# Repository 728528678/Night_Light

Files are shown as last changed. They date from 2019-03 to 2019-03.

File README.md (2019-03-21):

# Night_Light - The darkness need some light

## Night Light 是一个简单、灵活的小夜灯项目,要完成它你可能需要准备以下材料

### 元件清单
* 主控:		STM32F030F4P6		*1
* 触摸芯片:	TTP233D-HA6			*2
* 三极管: 	8050	*1 	8550	*1
* 降压芯片:	AMS1117 3.3v		*1
* 电容:		100nF	*15	100pF	*2
* USB转TTL:	CH340C				*1
* 二极管:	1N4148				*1
* 接插件:	4p排座	*1	4p排针	*1
* led灯:	白色贴片led			*4
* 电阻:		10KΩ	*6	1KΩ		*7
* USB接口:	TypeC 16pin 母座	*1
* 灯珠:		ws2812				*8
* 主控板:	NL_CTL2.0			*1
* 灯板:		NL_RGB2.0			*1

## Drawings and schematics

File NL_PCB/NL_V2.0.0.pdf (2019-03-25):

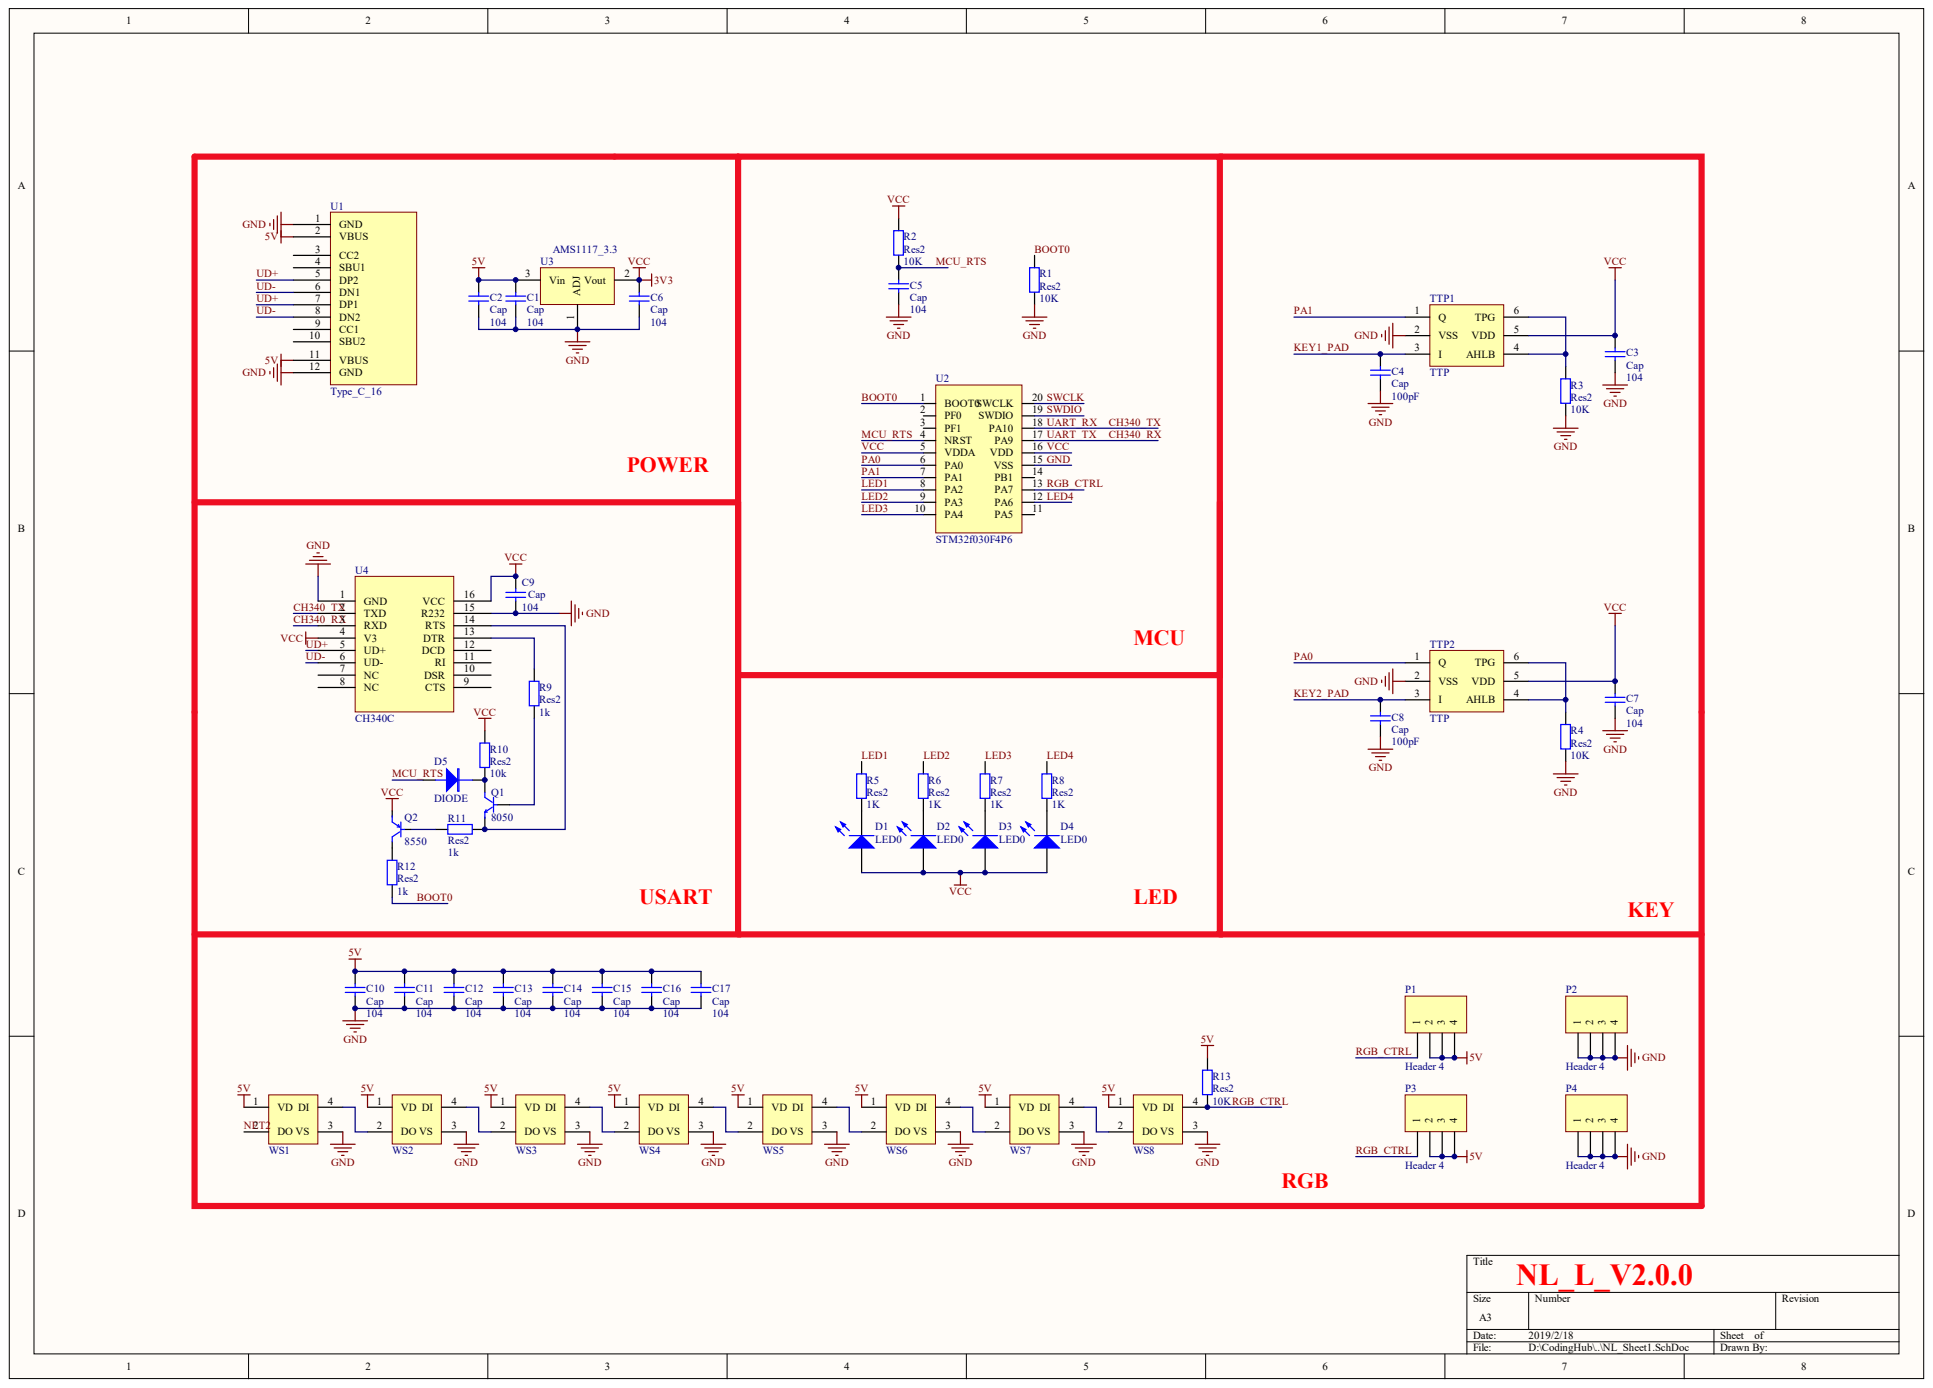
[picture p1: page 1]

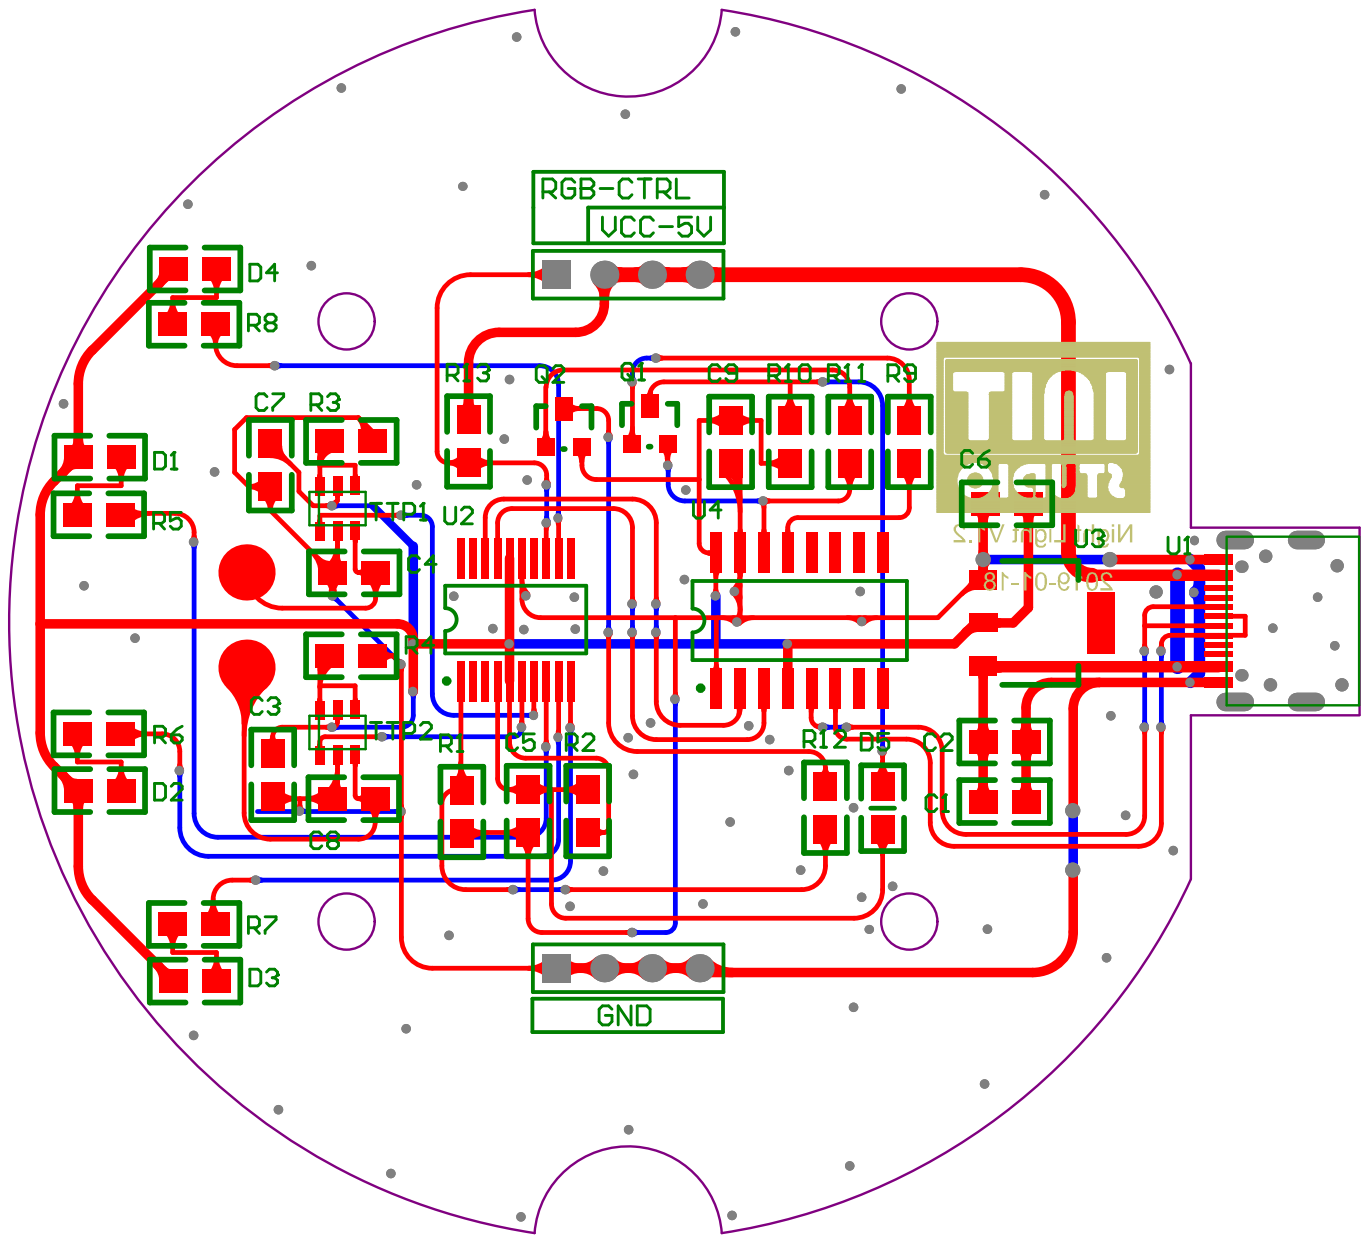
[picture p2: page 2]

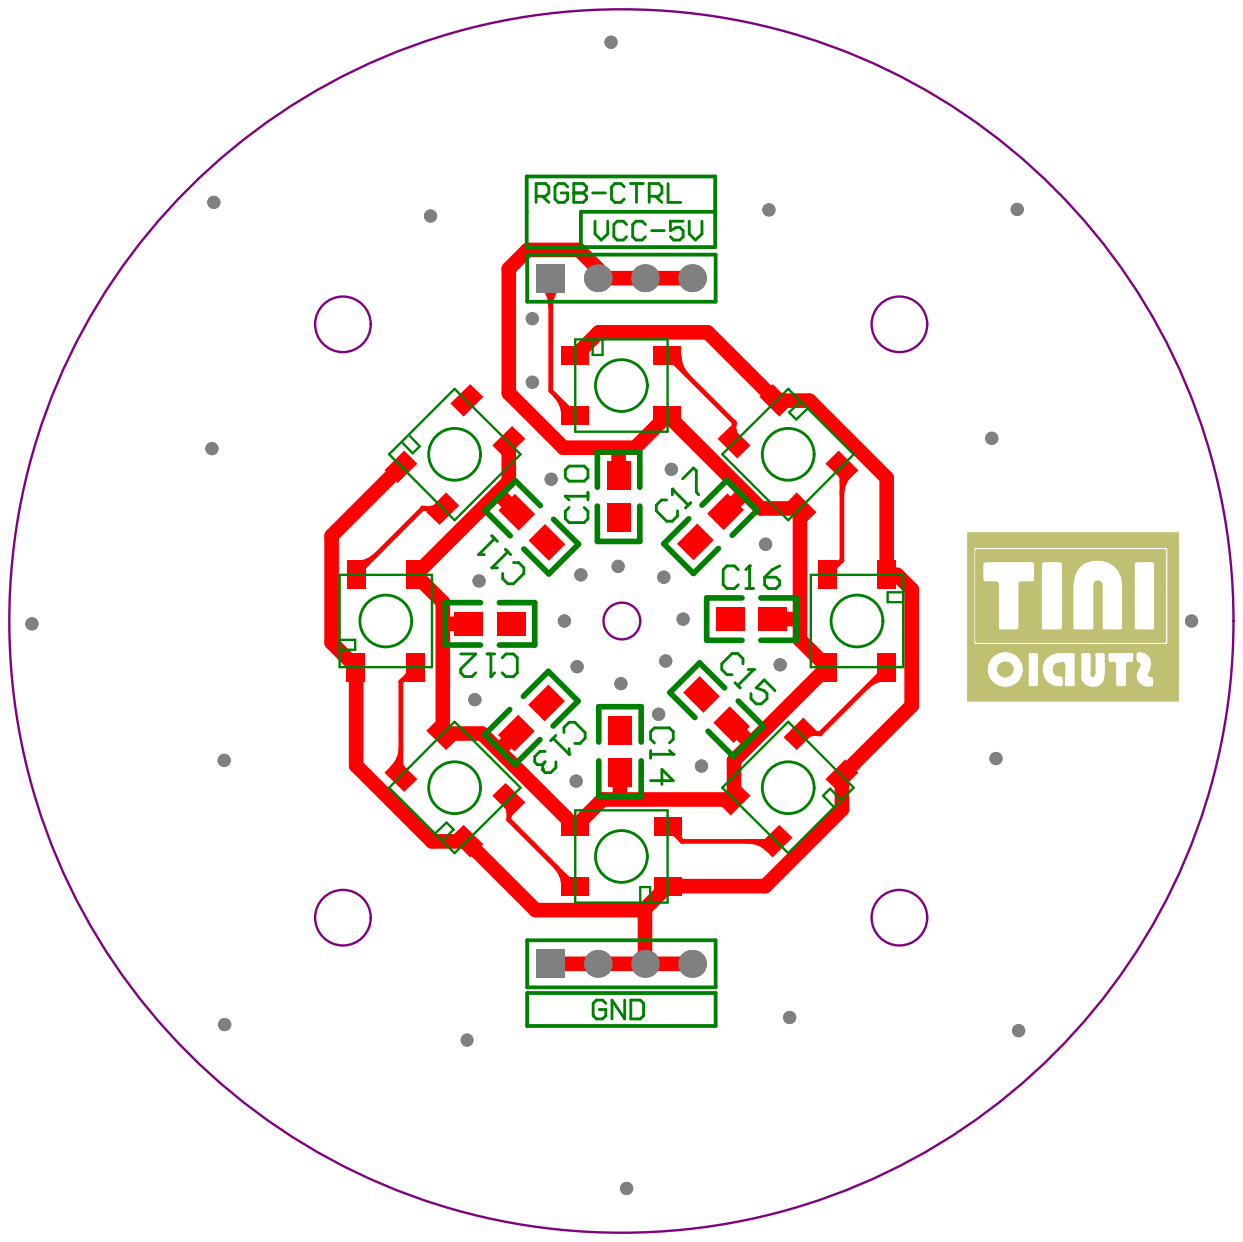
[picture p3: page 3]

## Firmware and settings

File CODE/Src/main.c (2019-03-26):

/**
  ******************************************************************************
  * @file           : main.c
  * @brief          : Main program body
  ******************************************************************************
  ** This notice applies to any and all portions of this file
  * that are not between comment pairs USER CODE BEGIN and
  * USER CODE END. Other portions of this file, whether 
  * inserted by the user or by software development tools
  * are owned by their respective copyright owners.
  *
  * COPYRIGHT(c) 2019 STMicroelectronics
  *
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
  ******************************************************************************
  */
/* Includes ------------------------------------------------------------------*/
#include "main.h"
#include "stm32f0xx_hal.h"
#include "dma.h"
#include "spi.h"
#include "tim.h"
#include "usart.h"
#include "gpio.h"

/* USER CODE BEGIN Includes */
#include "WS28.h"
#include "usercmd.h"
/* USER CODE END Includes */


/* USER CODE BEGIN PV */
                         
uint8_t ReceiveBuff[BUFFERSIZE];		//接收缓冲区
uint8_t recv_end_flag = 0,Rx_len;		//接收完成中断，接收到字符长度
uint8_t User_Run_flag = 0;
/* USER CODE END PV */

void SystemClock_Config(void);
static void MX_NVIC_Init(void);

/* USER CODE BEGIN PFP */
void WriteFlash(uint8_t addrnum,uint32_t data);
uint32_t ReadFlash(uint8_t addrnum);
void uartdamget(void);
/* USER CODE END PFP */

/* USER CODE BEGIN 0 */


uint32_t tim16,lasttim16;
uint8_t Color_Cnt;
uint8_t Work_Mode = Mode_Sleep;
uint8_t Sleep_State = Sleep_End;
uint32_t color_temp = 0;
uint32_t sys_color[3] = {RED,GREEN,BLUE};

//uint32_t WriteFlashData = 0x55555555;
//uint32_t ReadFlashData[4] ;
//uint32_t FlashAddr[3] = {0x08003400,0x08003800,0x08003C00};//0x08003000

#define FLASH_USER_START_PAGE 	 0x08003C00
#define FLASH_USER_SIZE					 5


#define Sleep_Min   						 10	//minutes
/* USER CODE END 0 */

/**
  * @brief  The application entry point.
  *
  * @retval None
  */
int main(void)
{
	/* MCU Configuration----------------------------------------------------------*/

	/* Reset of all peripherals, Initializes the Flash interface and the Systick. */
	HAL_Init();

	/* Configure the system clock */
	SystemClock_Config();

	  /* Initialize all configured peripherals */
	MX_GPIO_Init();
	MX_DMA_Init();
	MX_SPI1_Init();
	Sw28_Init(&hsw28,PIXELS_LEN);
	MX_TIM16_Init();
	MX_USART1_UART_Init();
	
	//colorWipe(&hsw28,BLACK,10);
	/* Initialize interrupts */
	MX_NVIC_Init();
	/* USER CODE BEGIN 2 */
	//Sw28_Init(&hsw28,PIXELS_LEN);
	HAL_TIM_Base_Start_IT(&htim16);

	/*        使能串口1 IDLE中断        */
	__HAL_UART_ENABLE_IT(&huart1, UART_IT_IDLE); 
	User_CMD_Init();
	uint8_t userdata_flag = 0;
	for(uint8_t i=0;i<3;i++)
	{
		sys_color[i] = ReadFlash(i);
		if(sys_color[i] == 0xFFFFFFFF)
		{
			sys_color[i] = RED;
			userdata_flag = 1;
		}
		else
		{
			userdata_flag = 0;
		}
	}
	if(userdata_flag == 1)
	{
		Show_Firstdown_inf();
	}
	
	/* USER CODE END 2 */

	/* Infinite loop */
	/* USER CODE BEGIN WHILE */
	while (1)
	{
	/* USER CODE END WHILE */
		uartdamget();
	/* USER CODE BEGIN 3 */
		if(Work_Mode == Mode_Bright)
		{
			colorWipe(&hsw28,sys_color[Color_Cnt-1],10);
		}
		else if(Work_Mode == Mode_Debug)
		{
			colorWipe(&hsw28,color_temp,10);
		}
		else if(Work_Mode == Mode_Breathe)
		{
			if(lasttim16 != tim16)
			{
				lasttim16 = tim16;
				Breathe_Show();		
			}
		}
		else
		{
			colorWipe(&hsw28,BLACK,10);
		}
//		if(Sleep_State==Sleep_Begin)
//		{
//			HAL_GPIO_WritePin(GPIOA, GPIO_PIN_4|GPIO_PIN_6|GPIO_PIN_9|GPIO_PIN_10, GPIO_PIN_SET);
//		}
//		else
//		{
//			HAL_GPIO_WritePin(GPIOA, GPIO_PIN_4|GPIO_PIN_6|GPIO_PIN_9|GPIO_PIN_10, GPIO_PIN_RESET);
//		}
	}
	/* USER CODE END 3 */

}

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
/* USER CODE BEGIN 4 */
void WriteFlash(uint8_t addrnum,uint32_t data)
{
	uint8_t i;
  uint32_t FlashDataTemp[FLASH_USER_SIZE]={0x00000000}; 
	for(i=0;i<FLASH_USER_SIZE;i++)
		FlashDataTemp[i] = ReadFlash(i);
	FlashDataTemp[addrnum] = data;
	
	HAL_FLASH_Unlock();

	FLASH_EraseInitTypeDef f;
	f.TypeErase = FLASH_TYPEERASE_PAGES;
	f.PageAddress = FLASH_USER_START_PAGE;
	f.NbPages = 1;

	uint32_t PageError = 0;

	HAL_FLASHEx_Erase(&f, &PageError);
	
	for(i=0;i<FLASH_USER_SIZE;i++)
		HAL_FLASH_Program(FLASH_TYPEPROGRAM_WORD, FLASH_USER_START_PAGE+4*i, FlashDataTemp[i]);

	HAL_FLASH_Lock();
}

uint32_t ReadFlash(uint8_t addrnum)
{
	uint32_t temp = *(__IO uint32_t*)(FLASH_USER_START_PAGE+4*addrnum);
	return temp;
}


void HAL_GPIO_EXTI_Callback(uint16_t GPIO_Pin)
{
  if(GPIO_Pin == GPIO_PIN_0)
  {
		while(HAL_GPIO_ReadPin(GPIOA,GPIO_PIN_0));
		if(Work_Mode==Mode_Bright)
		{
			Sleep_State=Sleep_Begin;
			Work_Mode = Mode_Breathe;
			Beathe_Init(&bre28,sys_color[Color_Cnt-1]);
			tim16 = 0;
		}
		else if(Work_Mode == Mode_Breathe)
		{	
			Sleep_State=Sleep_End;
			Work_Mode = Mode_Bright;
		}
  }  
	if(GPIO_Pin == GPIO_PIN_1)
  {
		if(Work_Mode != Mode_Breathe)
		{
			while(HAL_GPIO_ReadPin(GPIOA,GPIO_PIN_1));
			if(Color_Cnt<3)
			{
				Work_Mode = Mode_Bright;
				Color_Cnt++;
			}
			else
			{
				Work_Mode = Mode_Sleep;
				Color_Cnt = 0;
				tim16 = 0;
				Sleep_State=Sleep_End;
			}
		}
  } 
}

void HAL_TIM_PeriodElapsedCallback(TIM_HandleTypeDef *htim)
{
	//10ms
	if(htim == &htim16)
	{
		if(Sleep_State==Sleep_Begin)
		{	
			if(tim16<Sleep_Min*100*60)
			{	
				tim16++;
			}
			else
			{
				if(bre28.Status!=WAIT)
					tim16++;
				else
				{
					tim16=0;
					Sleep_State=Sleep_End;
					Work_Mode = Mode_Sleep;		
				}
			}		
		}
		
	} 
}

void uartdamget(void)
{
	if(recv_end_flag ==1)
	{
		if(User_Run_flag == 0)
		{
			User_Run_flag =1;
		}
		else
		{
			CMD_String_deal(ReceiveBuff);
		}
		/*        打印接收到的数据长度 */
		//printf("\nrx_len=%d\r\n",Rx_len);
		
		//Sw_Light_Color(color_temp);
//		for(int i=0;i<Rx_len;i++)
//		{
//		/*        打印接收到的数据 */
//			printf("%c",ReceiveBuff[i]);
//		}
//		printf("\r\n");   
//		printf("%#x\r\n",color_temp);
		
		/*        清空接收缓存区        */
		for(int i = 0; i < Rx_len ; i++) 
				ReceiveBuff[i]=0;
		/*        接收数据长度清零        */
		Rx_len=0;
		recv_end_flag=0;
	}
	/*        开启下一次接收        */
	HAL_UART_Receive_DMA(&huart1,(uint8_t*)ReceiveBuff,BUFFERSIZE);
}
/* USER CODE END 4 */
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


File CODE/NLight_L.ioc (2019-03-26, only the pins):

Mcu.UserName=STM32F030F4Px
PA0.Signal=GPXTI0
PA1.Signal=GPXTI1
PA10.Signal=USART1_RX
PA13.Signal=SYS_SWDIO
PA14.Signal=SYS_SWCLK
PA2.Signal=GPIO_Output
PA3.Signal=GPIO_Output
PA4.Signal=GPIO_Output
PA5.Signal=SPI1_SCK
PA6.Signal=GPIO_Output
PA7.Signal=SPI1_MOSI
PA9.Signal=USART1_TX

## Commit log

2019-03-04 修改readme.md
2019-03-21 增加元件清单
2019-03-21 格式修改
2019-03-21 修改.md
2019-03-25 Add pcb file and gitignore file
    [NL_CTL2.0.PcbDoc, NL_PCB_L.PcbDoc, NL_PCB_Project.PrjPCB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]

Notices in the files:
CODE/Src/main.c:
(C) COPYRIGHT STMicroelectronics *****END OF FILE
